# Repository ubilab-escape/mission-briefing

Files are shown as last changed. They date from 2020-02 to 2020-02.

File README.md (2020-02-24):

# Mission Briefing
The mission briefing provides the team members with the information they need to know before starting the game. It lets them understand the goal they need to achieve without giving too much details. The mission briefing device should self-destruct after the briefing is finished.

## Device Description
The device consists of a smartphone (Nexus 5) mounted on a smoke generator. An android app is used to play the briefing clip automatically once the app is started. At the end of the briefing clip, the app turns on the flash light of the smartphone camera in order to trigger the smoke generator. 

The smoke generator consists of an e-cigarette to which a small pump is attached. An LDR is used in order to detect the flash light. The signal from the LDR is detected using an Arduino nano microcontroller. The microcontroller turns on the e-cigarette for 10 seconds using a relay once the LDR is triggered.

## CAD Design
The smoke generator, shown in the figure below, was designed using FreeCAD software. It features an internal cavity that keeps the smoke away from the electronic circuitry. The smoke enters the cavity at the inlet and gets out from several slots placed around the smartphone at the surface.

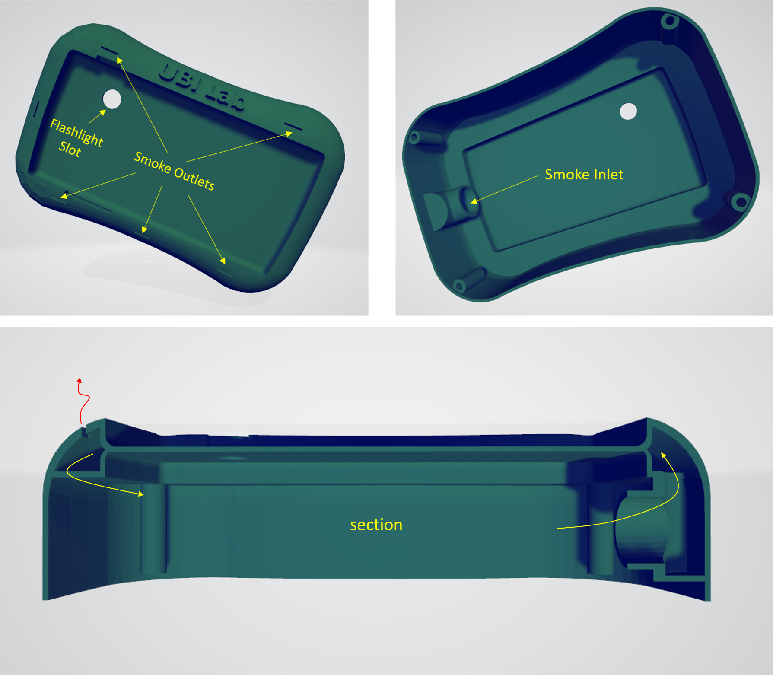
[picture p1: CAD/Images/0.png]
CAD Image


## Mission Briefing Clip
The mission briefing clip was implemented in Adobe After-Effect. A Cloud-Based text-to-speach (TTS) Api was used for presenting the mission. The TTS API can be found at: https://ttsdemo.com

## Android App
In order to automatically play the clip on the smartphone and trigger the flash light at the end, an app was required. The app was implemented in MIT App Inventor. App Inventor is a web-application integrated development environment which is very easy for beginners.

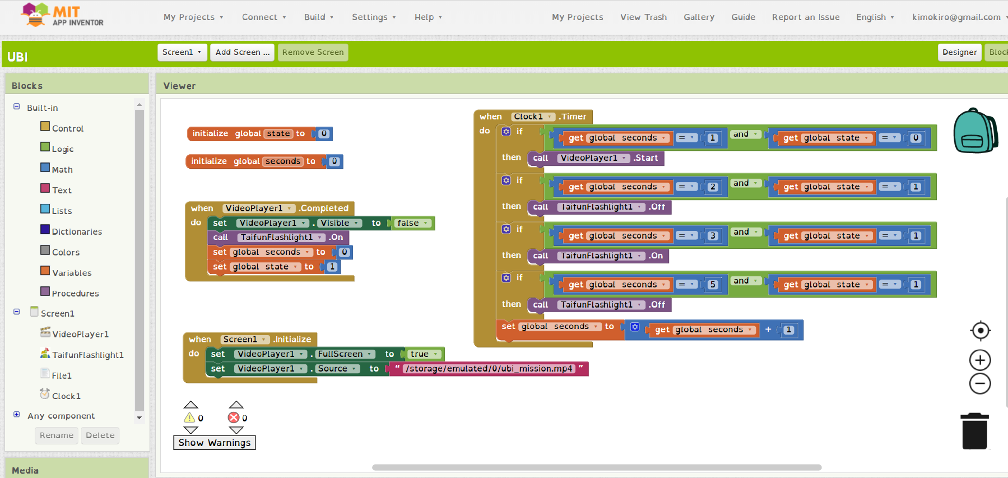
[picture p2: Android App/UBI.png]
App Image


## Electronics 
- MCU: Arduino Nano 
- LDR: 2mm LDR (non-RoHS)
- Reed Relay: Schneider Electric 117SIP-6 
- Resistor: 10K 
- Mini Pump: YYP031-3A1
- E-cigarette: CE-4
- Mini Breadboard
- Batteries : 9V and 4.5V (x3 1.5V)

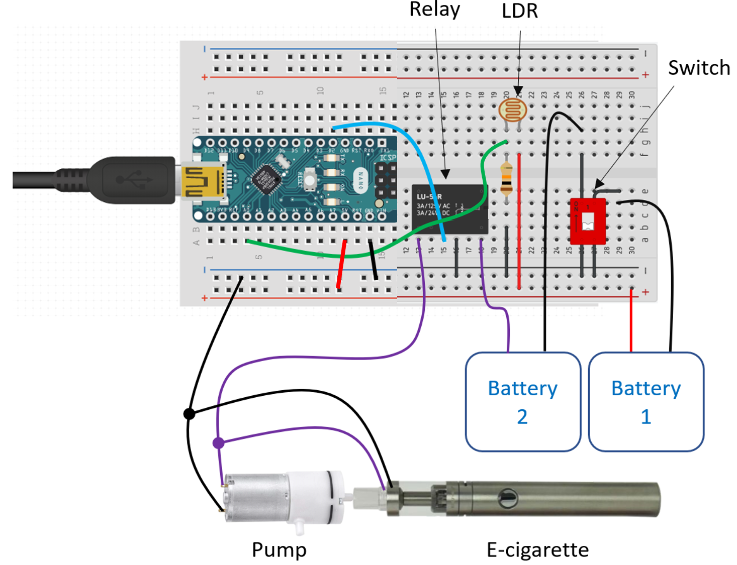
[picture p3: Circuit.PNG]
Circuit Image


## Integration notes for rebuilding the system
- 3D print the design (mesh files @ \CAD\Mesh Files)
- Flash the arduino with the code provided (code @ \Arduino\Arduino.ino).
- Connect the components as shown in the schematic (Circuit.PNG).
- Install the apk file provided on a Nexus 5 smartphone (file @ \Android App\UBI.apk).
- Place the ubi_mission.mp4 file into the home directory of the smartphone (file @ \Briefing Clip\ubi_mission.mp4).
- Mount the phone onto the smoke machine and run the app!

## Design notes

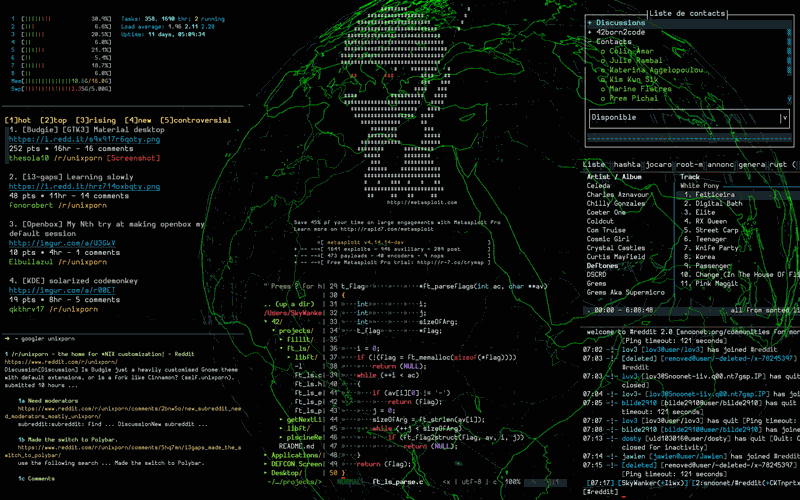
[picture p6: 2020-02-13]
Briefing Clip/(Footage)/01. Edit Comp/Images/1514301135_urkkgd4u8uty.gif

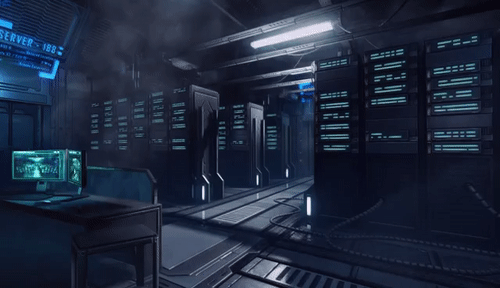
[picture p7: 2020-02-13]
Briefing Clip/(Footage)/01. Edit Comp/Images/GivingSpryGrouper-size_restricted.gif

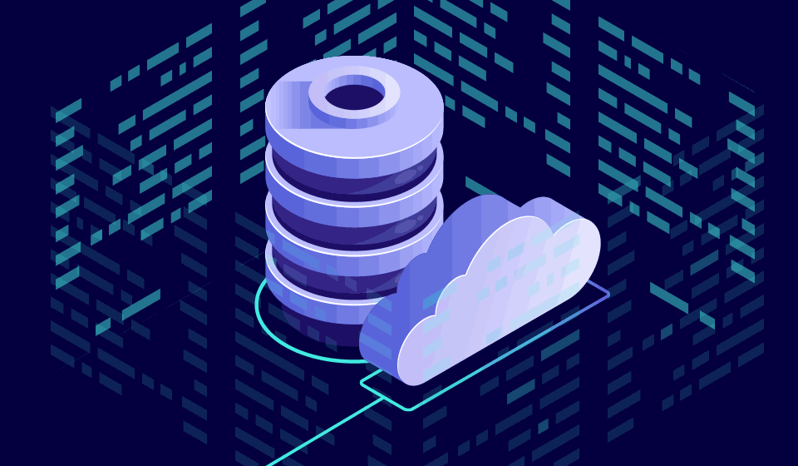
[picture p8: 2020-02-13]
Briefing Clip/(Footage)/01. Edit Comp/Images/6thNovBlogImageAnimated.gif

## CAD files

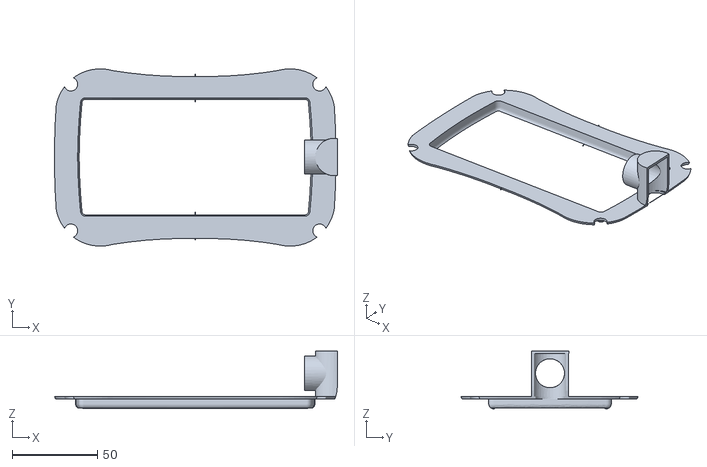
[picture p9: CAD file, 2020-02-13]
CAD/Mesh Files/hosuing_part2.stl
166.1 x 104.0 x 33.9

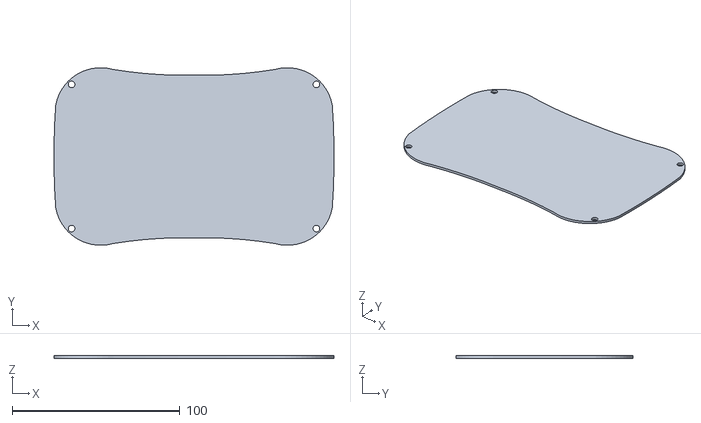
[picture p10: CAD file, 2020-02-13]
CAD/Mesh Files/cover.stl
167.0 x 105.8 x 1.50

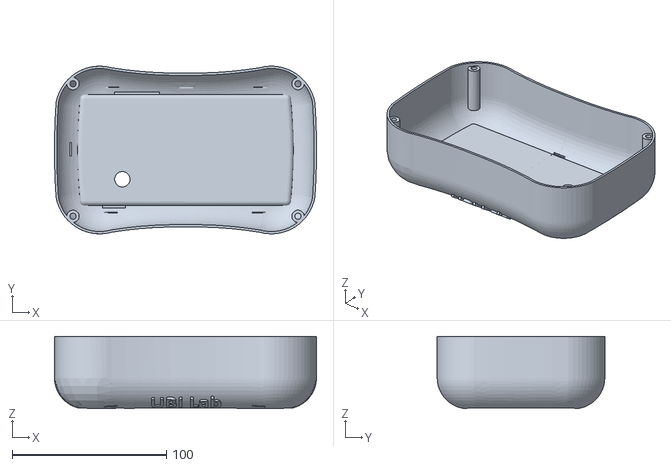
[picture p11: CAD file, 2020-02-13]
CAD/Mesh Files/housing_part1.stl
170.0 x 108.8 x 47.0

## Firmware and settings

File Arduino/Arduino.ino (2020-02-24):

const int LDR = A0;     // LDR analog pin
const int trigger = 2;  // Relay control pin

void setup() {
  pinMode(LDR, INPUT);      // Initialize LDR pin as input
  pinMode(trigger, OUTPUT); // Initialize trigger pin as output
}

void loop() {
  int light = analogRead(LDR);      // read analog value (0 - 1023)
  if(light > 600){                  // if flash light is on
    digitalWrite(trigger, HIGH);    // switch on the relay
    delay(10*1000);                 // wait 10 seconds
  }
}
